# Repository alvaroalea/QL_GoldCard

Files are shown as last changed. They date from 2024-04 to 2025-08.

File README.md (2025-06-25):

# QL_GoldCard
A reverse engineering exercice using the Sinclair QL GoldCard Expansion Card as target

Licensed under Cern OHL-S - https://ohwr.org/cern_ohl_s_v2.txt

(The 3D Model of the PLCC chips is work of Zerover)

## WARNING: DO NOT USE THIS PROJECT IS NOT TESTED AND MISSING THINGS
This is not a functional item, it's only a exercice of reverse engineering to reinforce my skills in Kicad EDA Software.

This project match schematics found on internet, and pictures of the real interface.

* There is no know source of the JEDEC file for the Altera's CPLD
* Some IC can be deprecated and not found on market.
* No information about original has 2 or 4 copper layer, I just use 4, as I was not able to do it in only 2.

Anyway:
* There is not error or warning on the PCB and Schematics
* Schematics seen to be good
* Copper side match 1:1 pictures of internet.

For that:
* If you take the risk and do one and it work, please let me know.
* If you have the source of JEDEC file for the CPLD, please let me know.
* If you found any error in the schematic or PLC, please, let me know.

Two folder
* Original - The design as similar as posible to the Miracles design.
* Alea - new design with new footprints.

## The GoldCard Board
This card is a upgrade of the Sinclair QL computer from 1985, it provide a 68000 processor running a 16Mhz and with a bus wide of 16bit, against original 68008, 7,5Mhz and 8bits bus wide, this is theorically 4 times faster than original QL.

Provide Aditional 1920Mb of Ram (16bits) of 2048Mb installed. (128Kb are used as shadow Rom)

Include a up to 4 disk drive (3 + 1 with a add-on card) compatible with 720Kb, 1.44Mb and 2.88Mb (up to 3.2Mb depend of the format)

It have a Real Time Clock.

This was later superseded by the SuperGoldCard, that use a 68020/24Mhz and 4Mb of Ram.

There area at least 3 Version of the PCB, this is based on the lastes one, version 1 was usually yellow, version 2 and 3 was red color.

Version 1 and 2 have a capacitor solder between CLK and GND under the 68000, and a 3-pad solder jumper under the floppy controller.

CPLD have a sticker over it, "INGOT 6" for version 1 & 2, and "INGOT 5" on Golcard 3

## Comparative
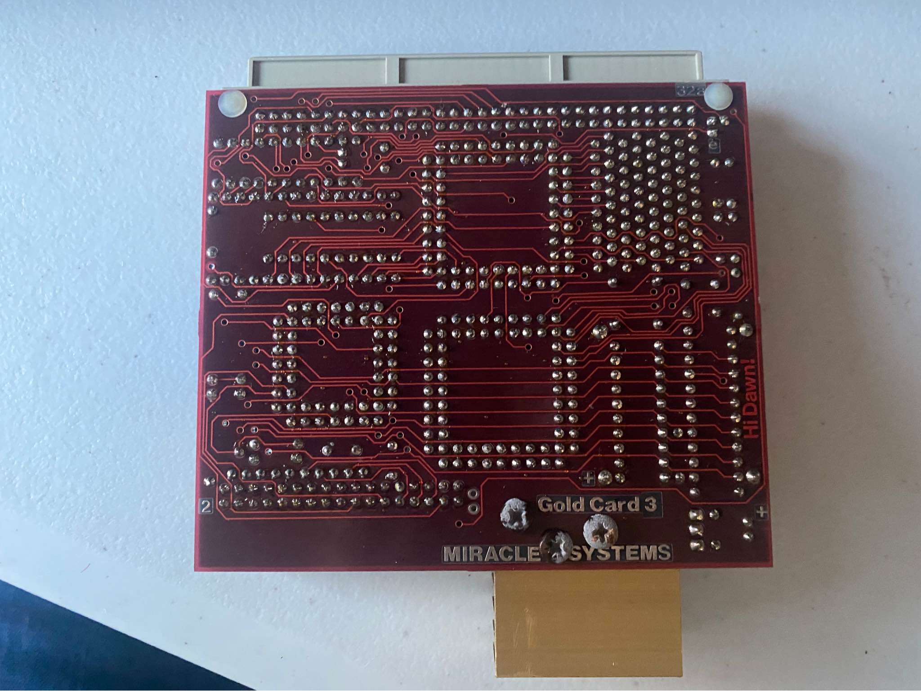
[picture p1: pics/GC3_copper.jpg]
Original Copper Side

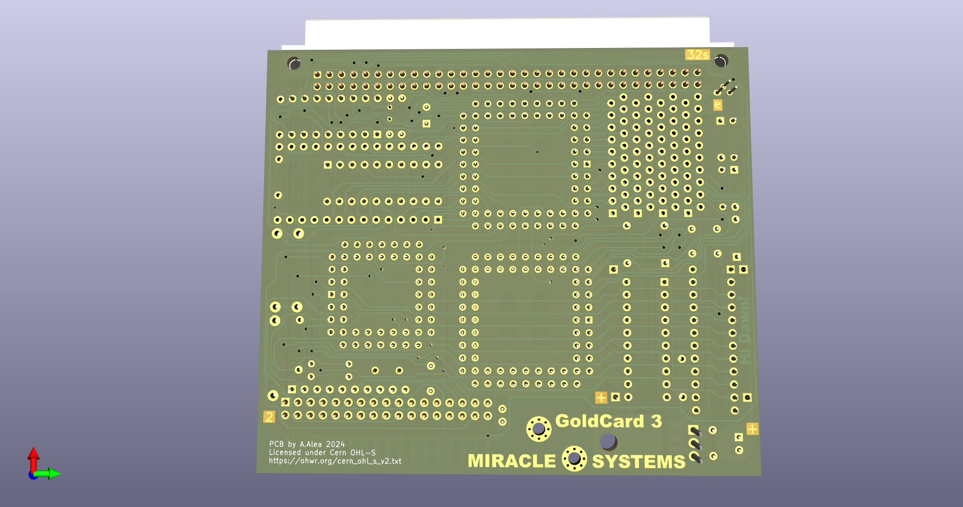
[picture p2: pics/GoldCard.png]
My Copper Side

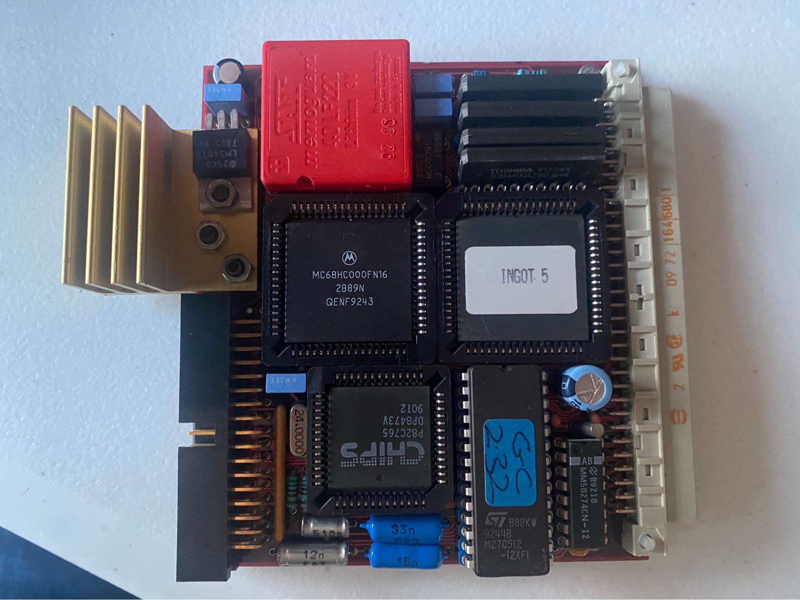
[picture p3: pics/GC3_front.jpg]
Original Components Side

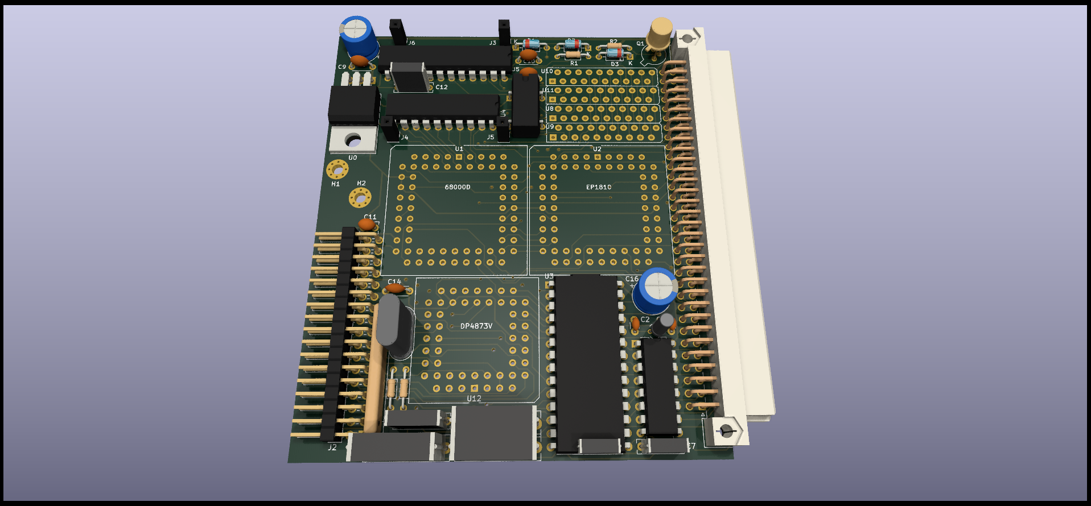
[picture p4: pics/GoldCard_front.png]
My Components Side


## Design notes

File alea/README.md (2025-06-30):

# QL GoldCard (Alea's Version)
A reverse engineering exercice using the Sinclair QL GoldCard Expansion Card as target

Licensed under Cern OHL-S - https://ohwr.org/cern_ohl_s_v2.txt

(The 3D Model of the PLCC chips is work of Zerover)

## WARNING: DO NOT USE THIS PROJECT IS NOT TESTED AND MISSING THINGS
This is not a functional item, it's only a exercice of reverse engineering to reinforce my skills in Kicad EDA Software.

* Use memory SIP-24 easy to found.
* No IC over IC
* small but in market battery socket
* 9V/5V jumpers for use with aurora or backplanes.

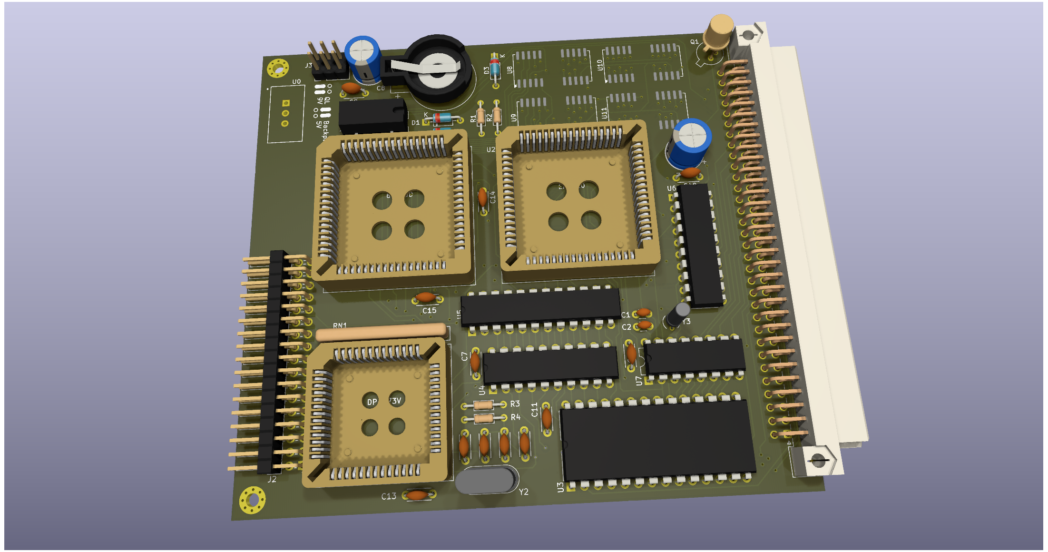
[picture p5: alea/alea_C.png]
My Components Side

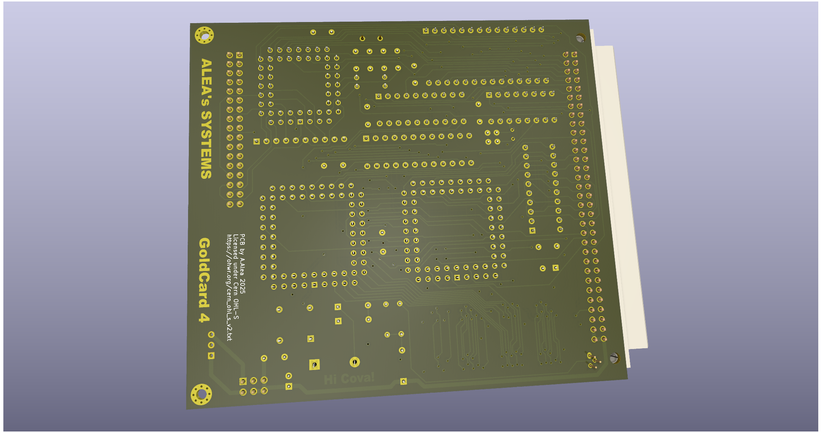
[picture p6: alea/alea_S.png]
My Copper Side


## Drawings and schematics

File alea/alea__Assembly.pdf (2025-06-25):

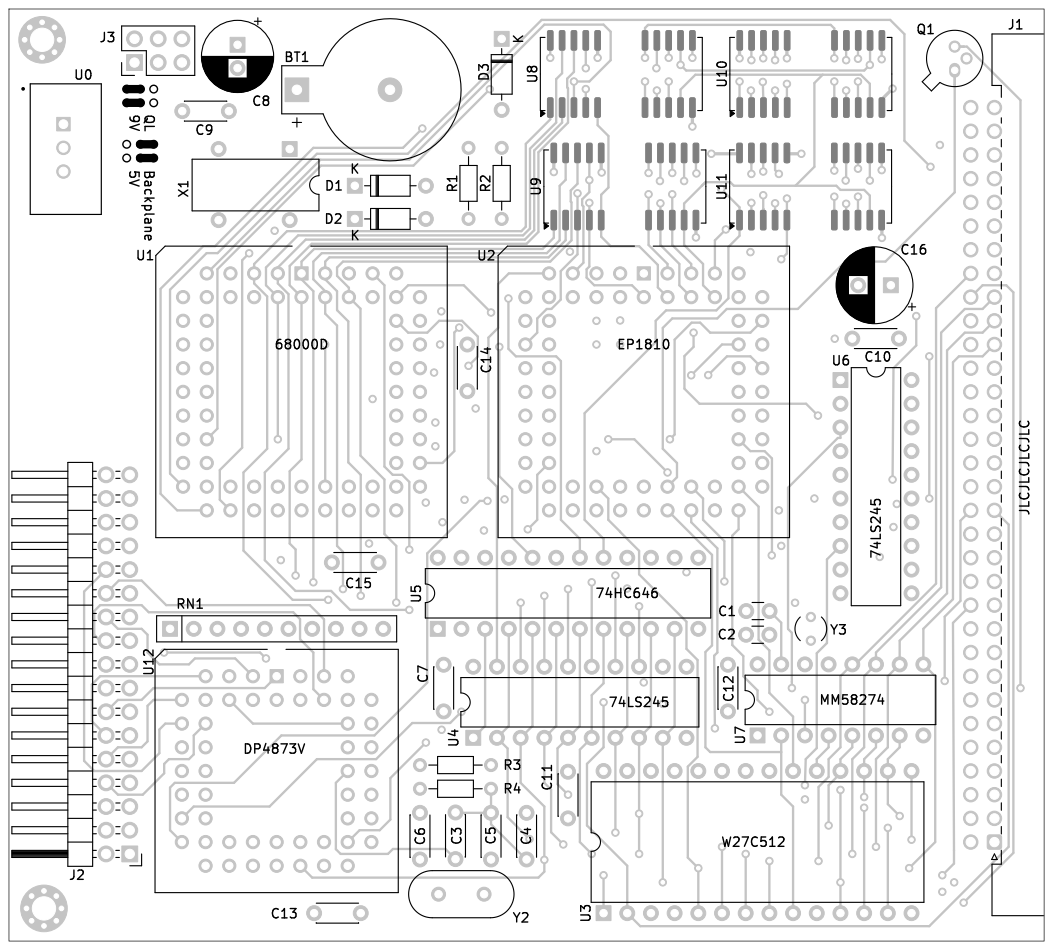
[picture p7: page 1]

Id: /1 Title: Sinclair QL Gold Card 3

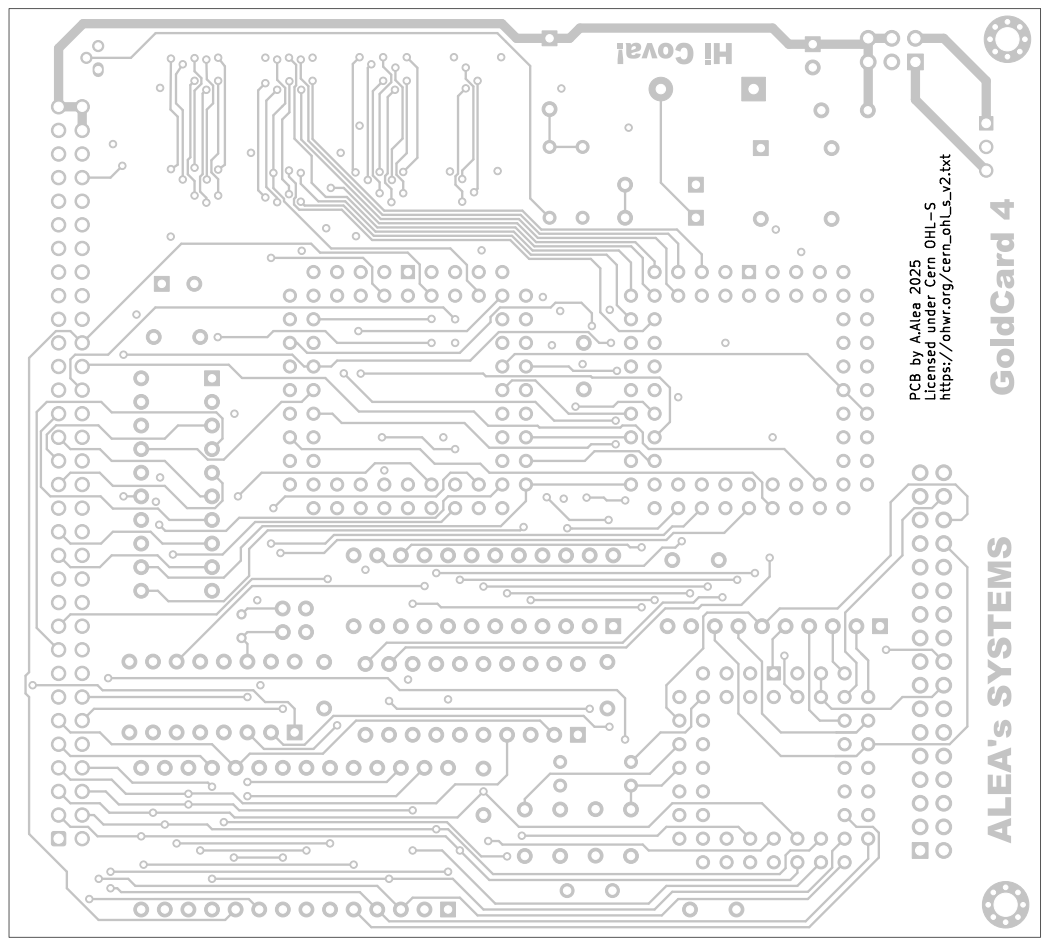
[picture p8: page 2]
D Date: 2024-04-14 KiCad; E.D.A. 9.0.2 Size: A4; Rev: 0.0; File: alea.kicad_pcb Sheet: Black; And; White; BOT Alvaro Alea Based; on schematic; from tetroid; Licensed; under Cern OHL-S -; https://ohwr.org/cern_ohl_s_v2.txt Board2Pdf:; Black; BOT -; Page 2/4

PCB by A.Alea 2025 Licensed under Cern OHL-S https://ohwr.org/cern_ohl_s_v2.txt

Id: /1 Title: Sinclair QL Gold Card 3

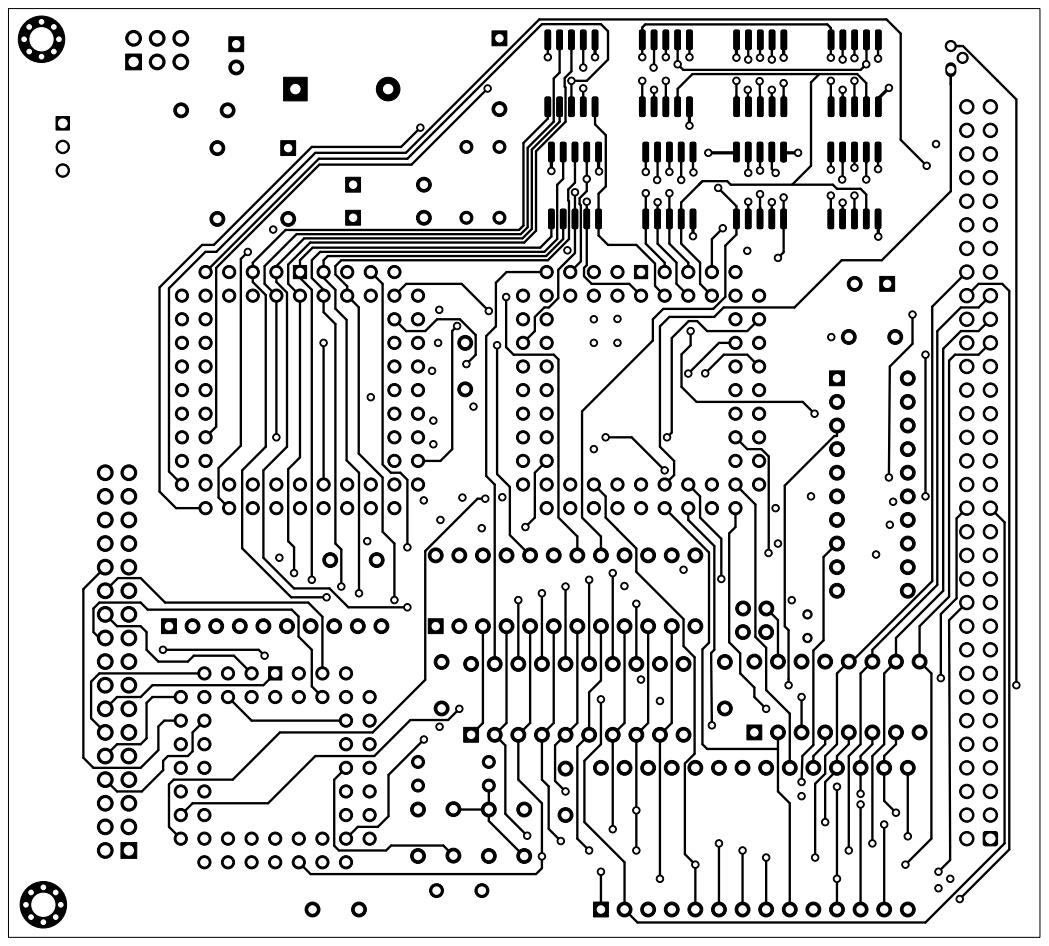
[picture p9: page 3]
D Date: 2024-04-14 KiCad; E.D.A. 9.0.2 Size: A4; Rev: 0.0; File: alea.kicad_pcb Sheet: Black; And; White; TOP-Tracks Alvaro Alea Based; on schematic; from tetroid; Licensed; under Cern OHL-S -; https://ohwr.org/cern_ohl_s_v2.txt Board2Pdf:; Black; TOP-Tracks; Page 3/4

Id: /1 Title: Sinclair QL Gold Card 3

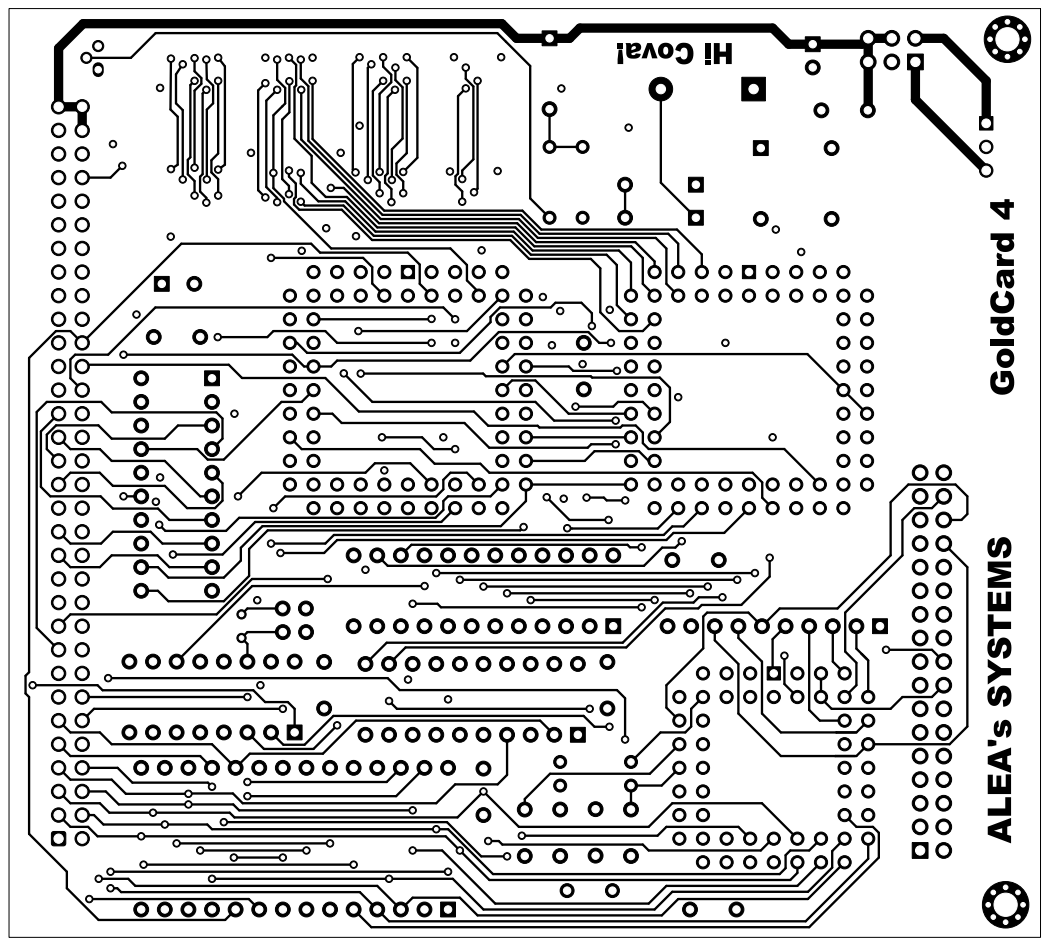
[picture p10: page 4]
D Date: 2024-04-14 KiCad; E.D.A. 9.0.2 Size: A4; Rev: 0.0; File: alea.kicad_pcb Sheet: Black; And; White; BOT-Tracks Alvaro Alea Based; on schematic; from tetroid; Licensed; under Cern OHL-S -; https://ohwr.org/cern_ohl_s_v2.txt Board2Pdf:; Black; BOT-Tracks; Page 4/4

Id: /1 Title: Sinclair QL Gold Card 3

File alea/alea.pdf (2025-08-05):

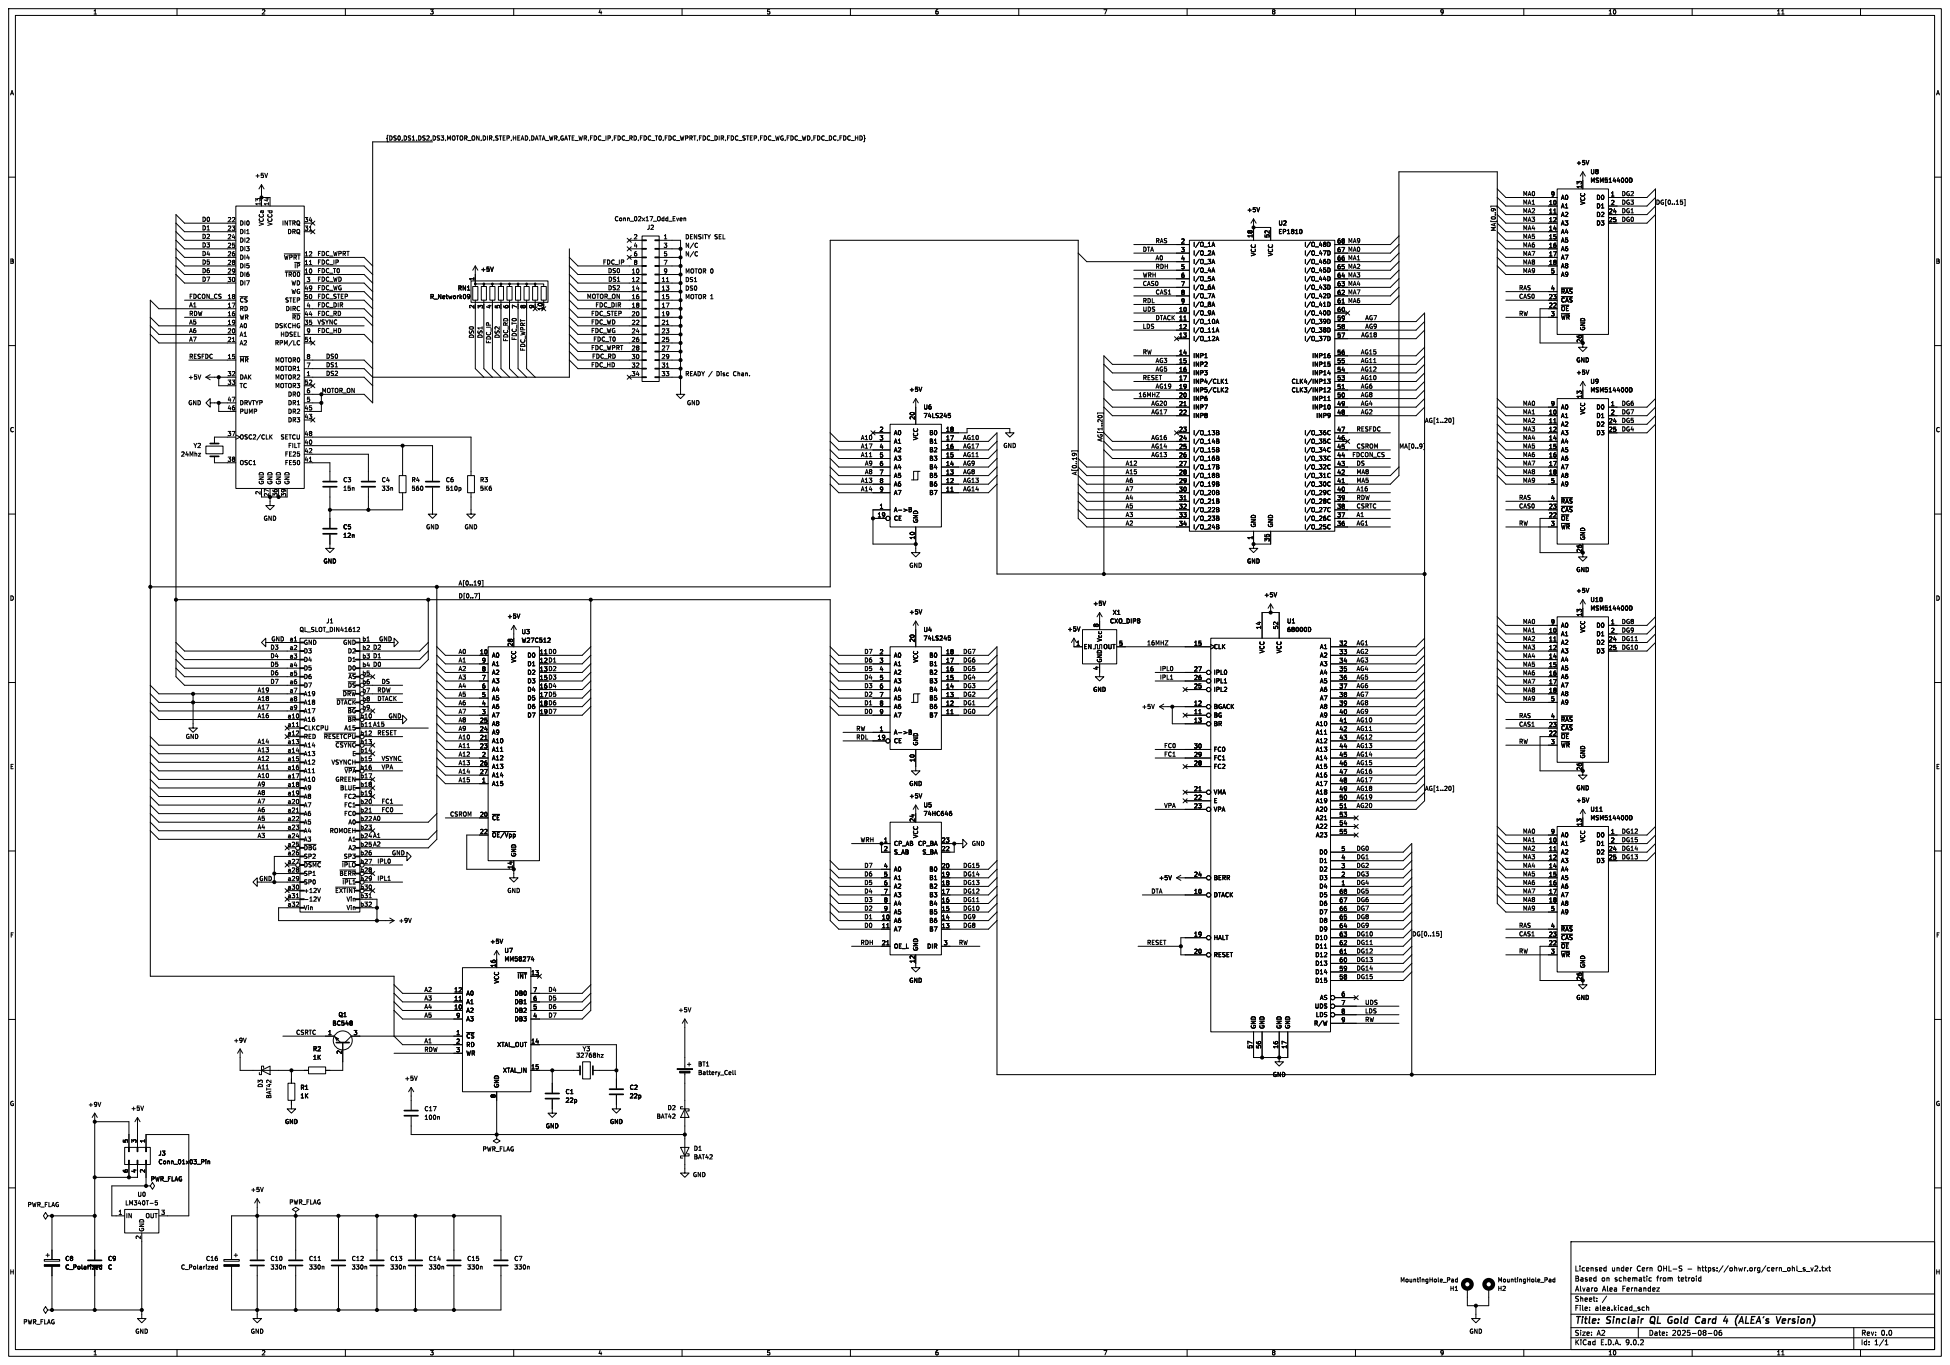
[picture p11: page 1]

+5V GND GND GND GND

2 VCCd 14 GND 27 GND 36 GND 39

J2 Conn_02x17_Odd_Even
DS1 MOTOR 0 MOTOR 1 DS0 READY / Disc Chan. DENSITY SEL

910 +5V U3 W27C512 A0 10 A1 9 A2 8 A3 7 A4 6 A5 5 A6 4 A7 3 A8 25 A9 24 A10 21 A11 23 A12 2 A13 26 A14 27 A15 1 ~{CE} 20 ~{OE/Vpp} 22 VCC 28 GND 14 D0 11 D1 12 D2 13 D3 15 D4 16 D5 17 D6 18 D7 19 +5V

b14 VSYNCH b15 ~{VPA}b16 GREEN b17 BLUE b18 FC2 b19 FC1 b20 FC0 b21 A0 b22 ROMOEH b23 A1 b24 A2 b25 SP3 b26 ~{IPLO}b27 ~{BERR}b28 ~{IPL1}b29 ~{EXTINT}b30 Vin b31 Vin b32

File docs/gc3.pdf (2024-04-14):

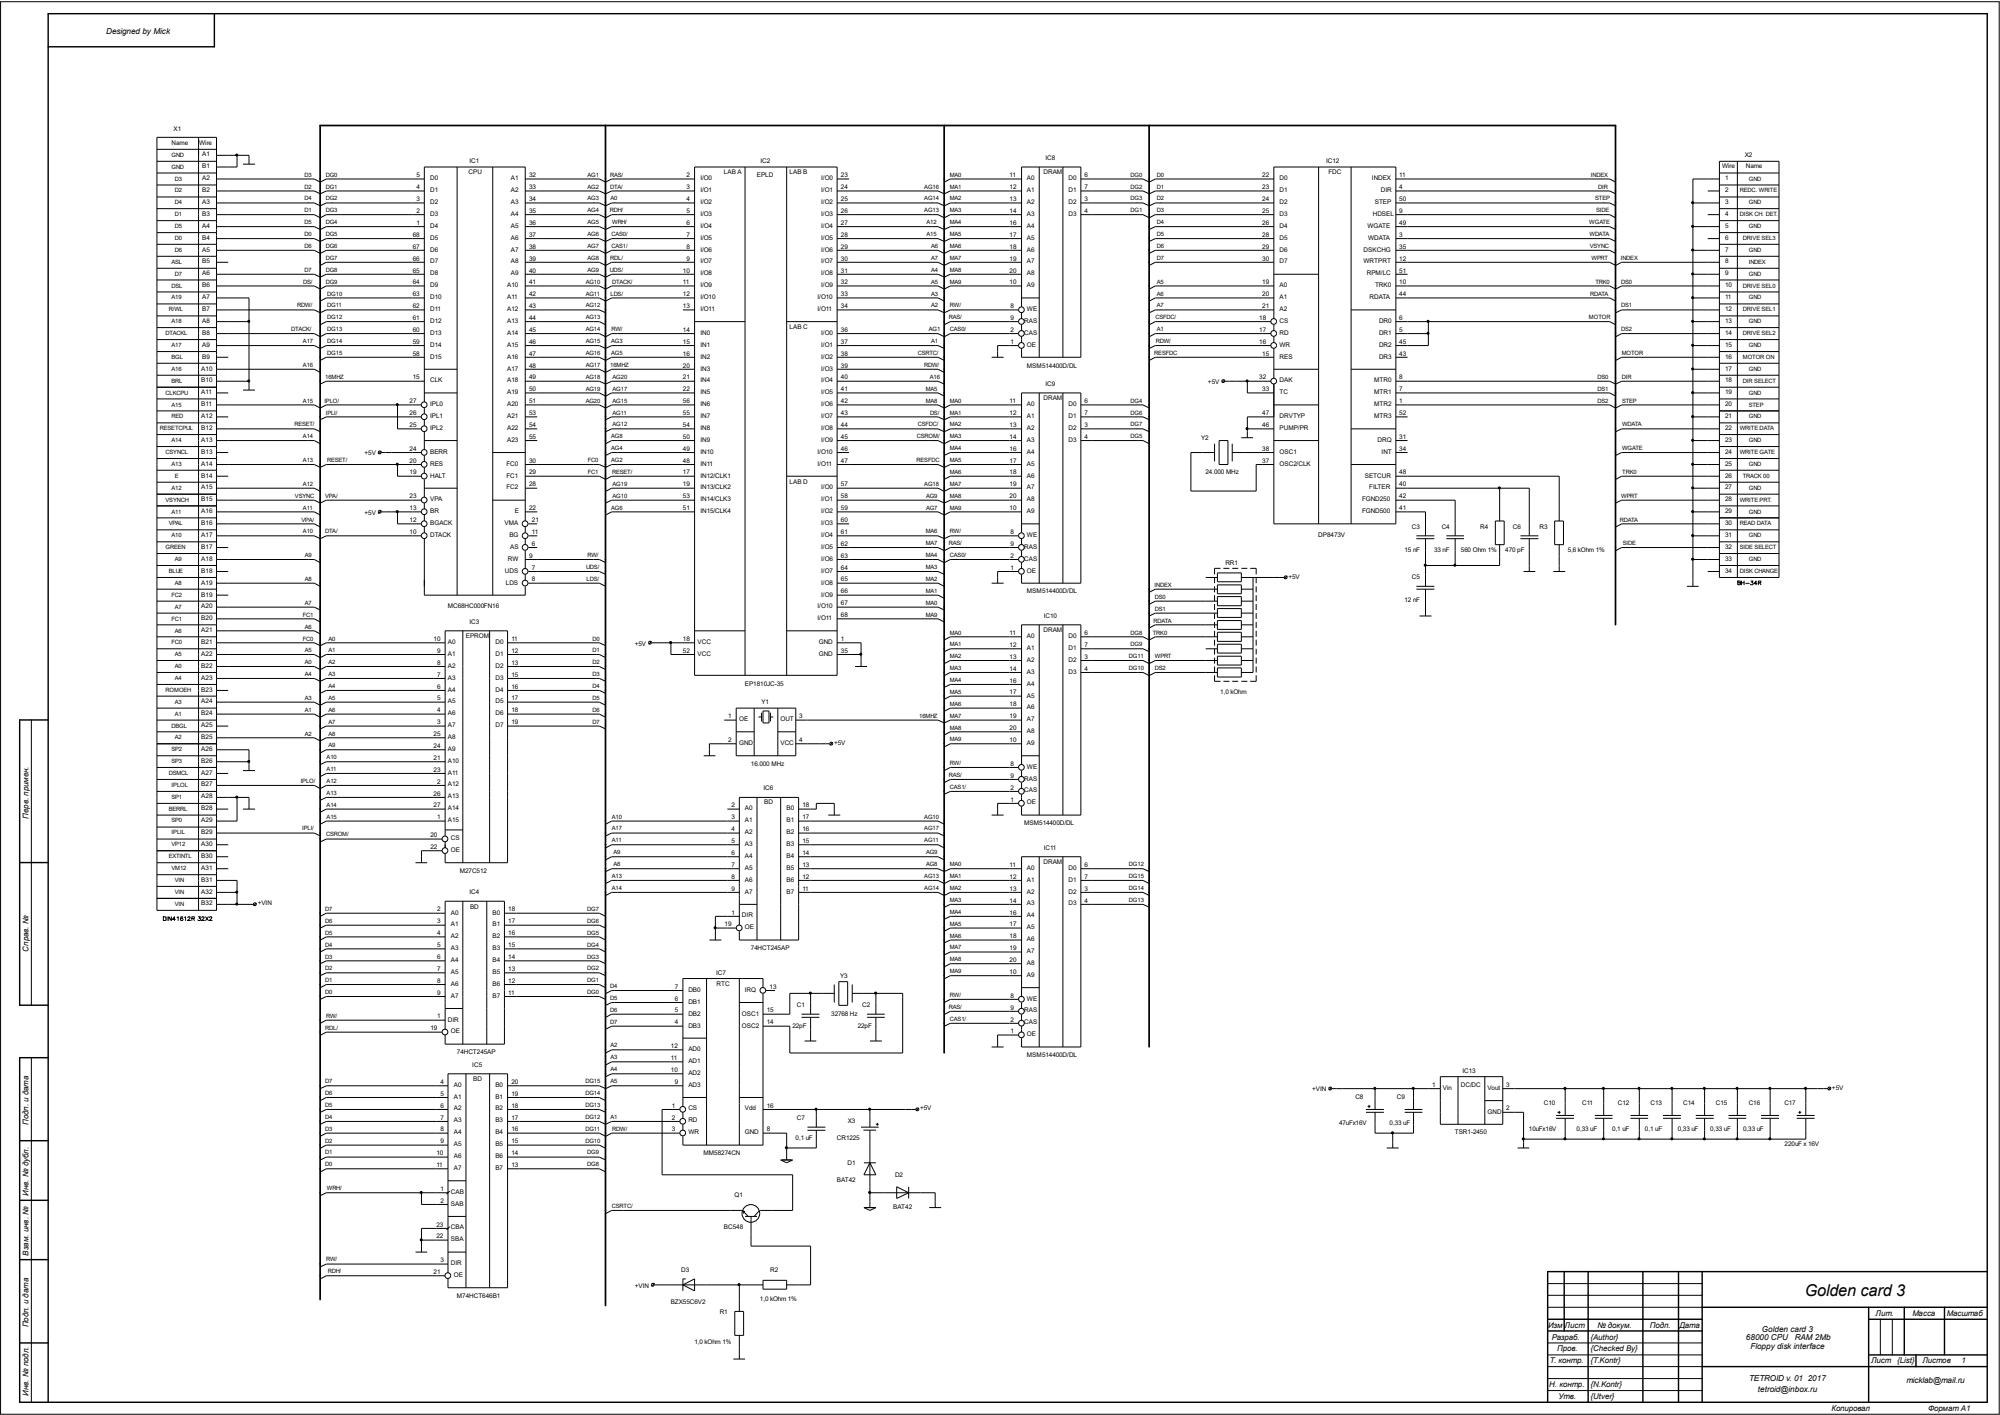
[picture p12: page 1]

Name | Wire

GND | A1

Инв. № подл. Подп. и дата Взам. инв. № Справ. № Перв. примен.

DSMCL | A27

IPLOL | B27

Инв. № дубл. Подп. и дата

Golden card 3

Golden card 3 68000 CPU RAM 2Mb Floppy disk interface | Лит. | Масса | Масштаб

Изм Лист | | № докум. | Подп. | Дата
Разраб. | | {Author}
Пров. | | {Checked By}
Т. контр. | {T.Kontr} | | | | Лист {List} | Листов 1

TETROID v. 01 2017 tetroid@inbox.ru | micklab@mail.ru

Н. контр. | {N.Kontr}
Утв. | {Utver}

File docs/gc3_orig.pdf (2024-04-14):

### Designed by Mick

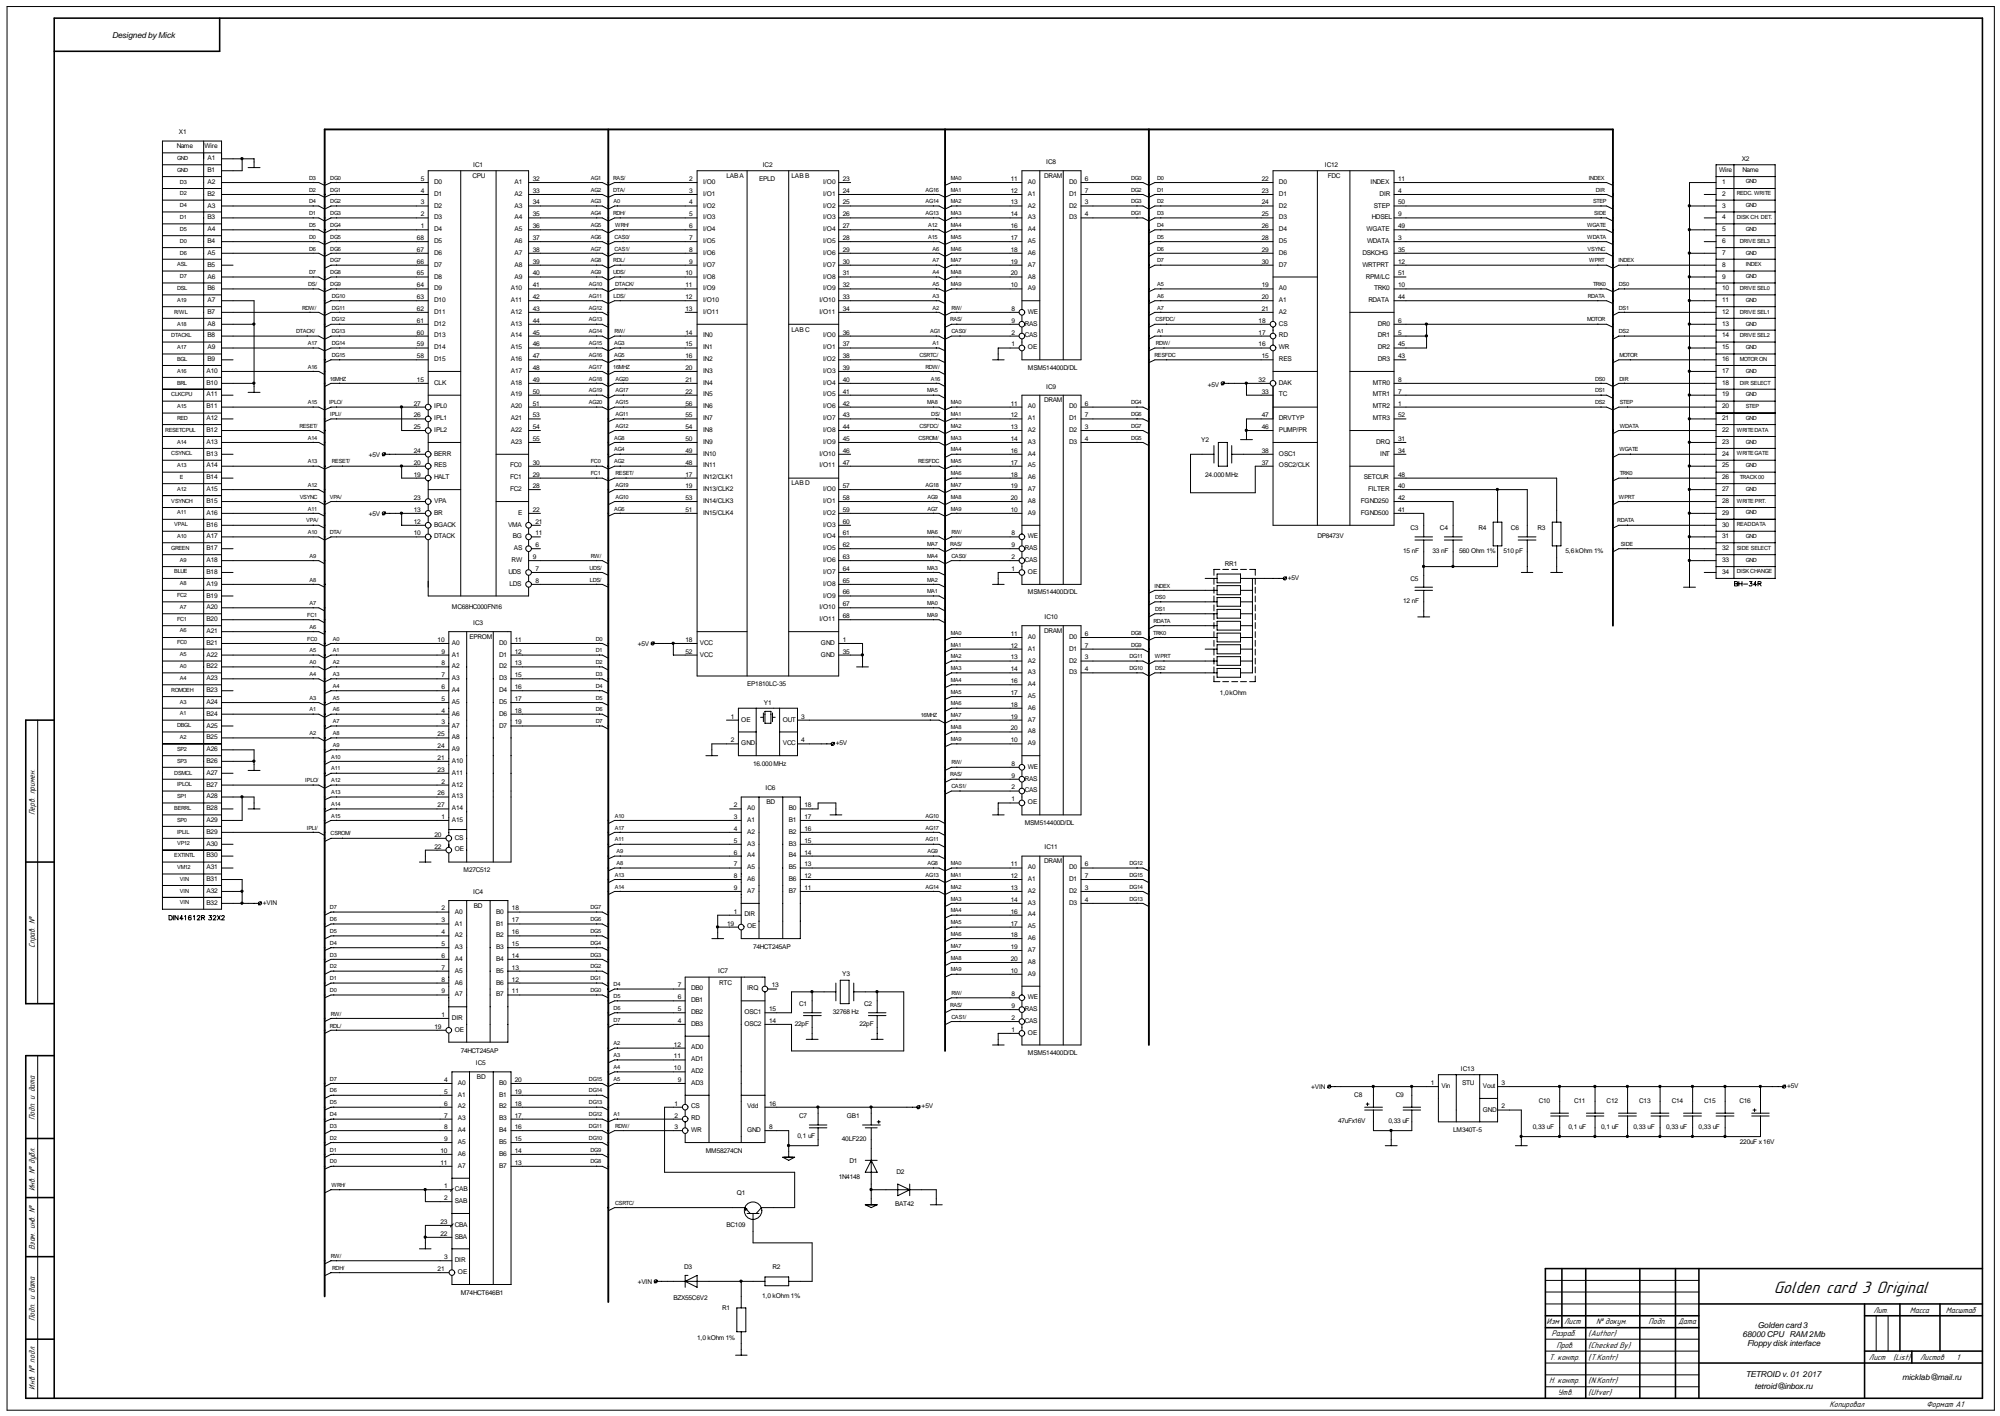
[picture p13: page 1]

A6
FC0 | B21

VCC | GND

Èíâ. ¹ ïîäë. Ïîäï. è äàòà Âçàì. èíâ. ¹ Ñïðàâ. ¹ Ïåðâ. ïðèìåí.

DSMCL | A27

IPLOL | B27

VIN | B32

VIN | A32

Èíâ. ¹ äóáë. Ïîäï. è äàòà

Golden card 3 Original

Èçì Ðàçðàá. Ïðîâ. Ò. êîíòð. | ¹ äîêóì. {Author} {Checked By} {T.Kontr} | Ïîäï. | Äàòà Ëèñò Golden card 3 68000 CPU RAM 2Mb Floppy disk interface | Ëèò. Ìàññà Ìàñøòàá

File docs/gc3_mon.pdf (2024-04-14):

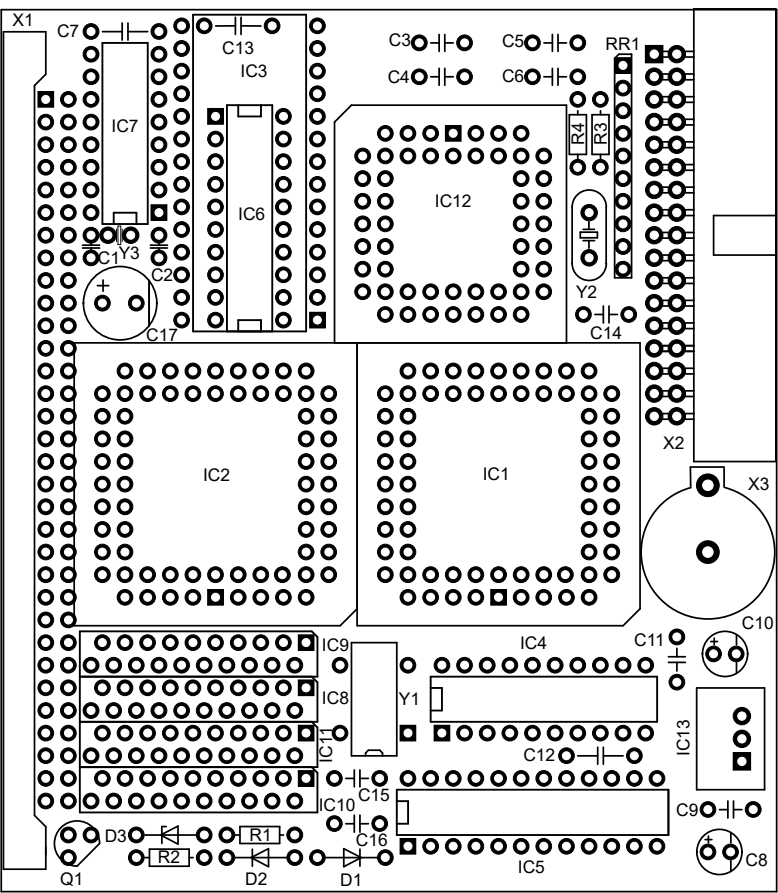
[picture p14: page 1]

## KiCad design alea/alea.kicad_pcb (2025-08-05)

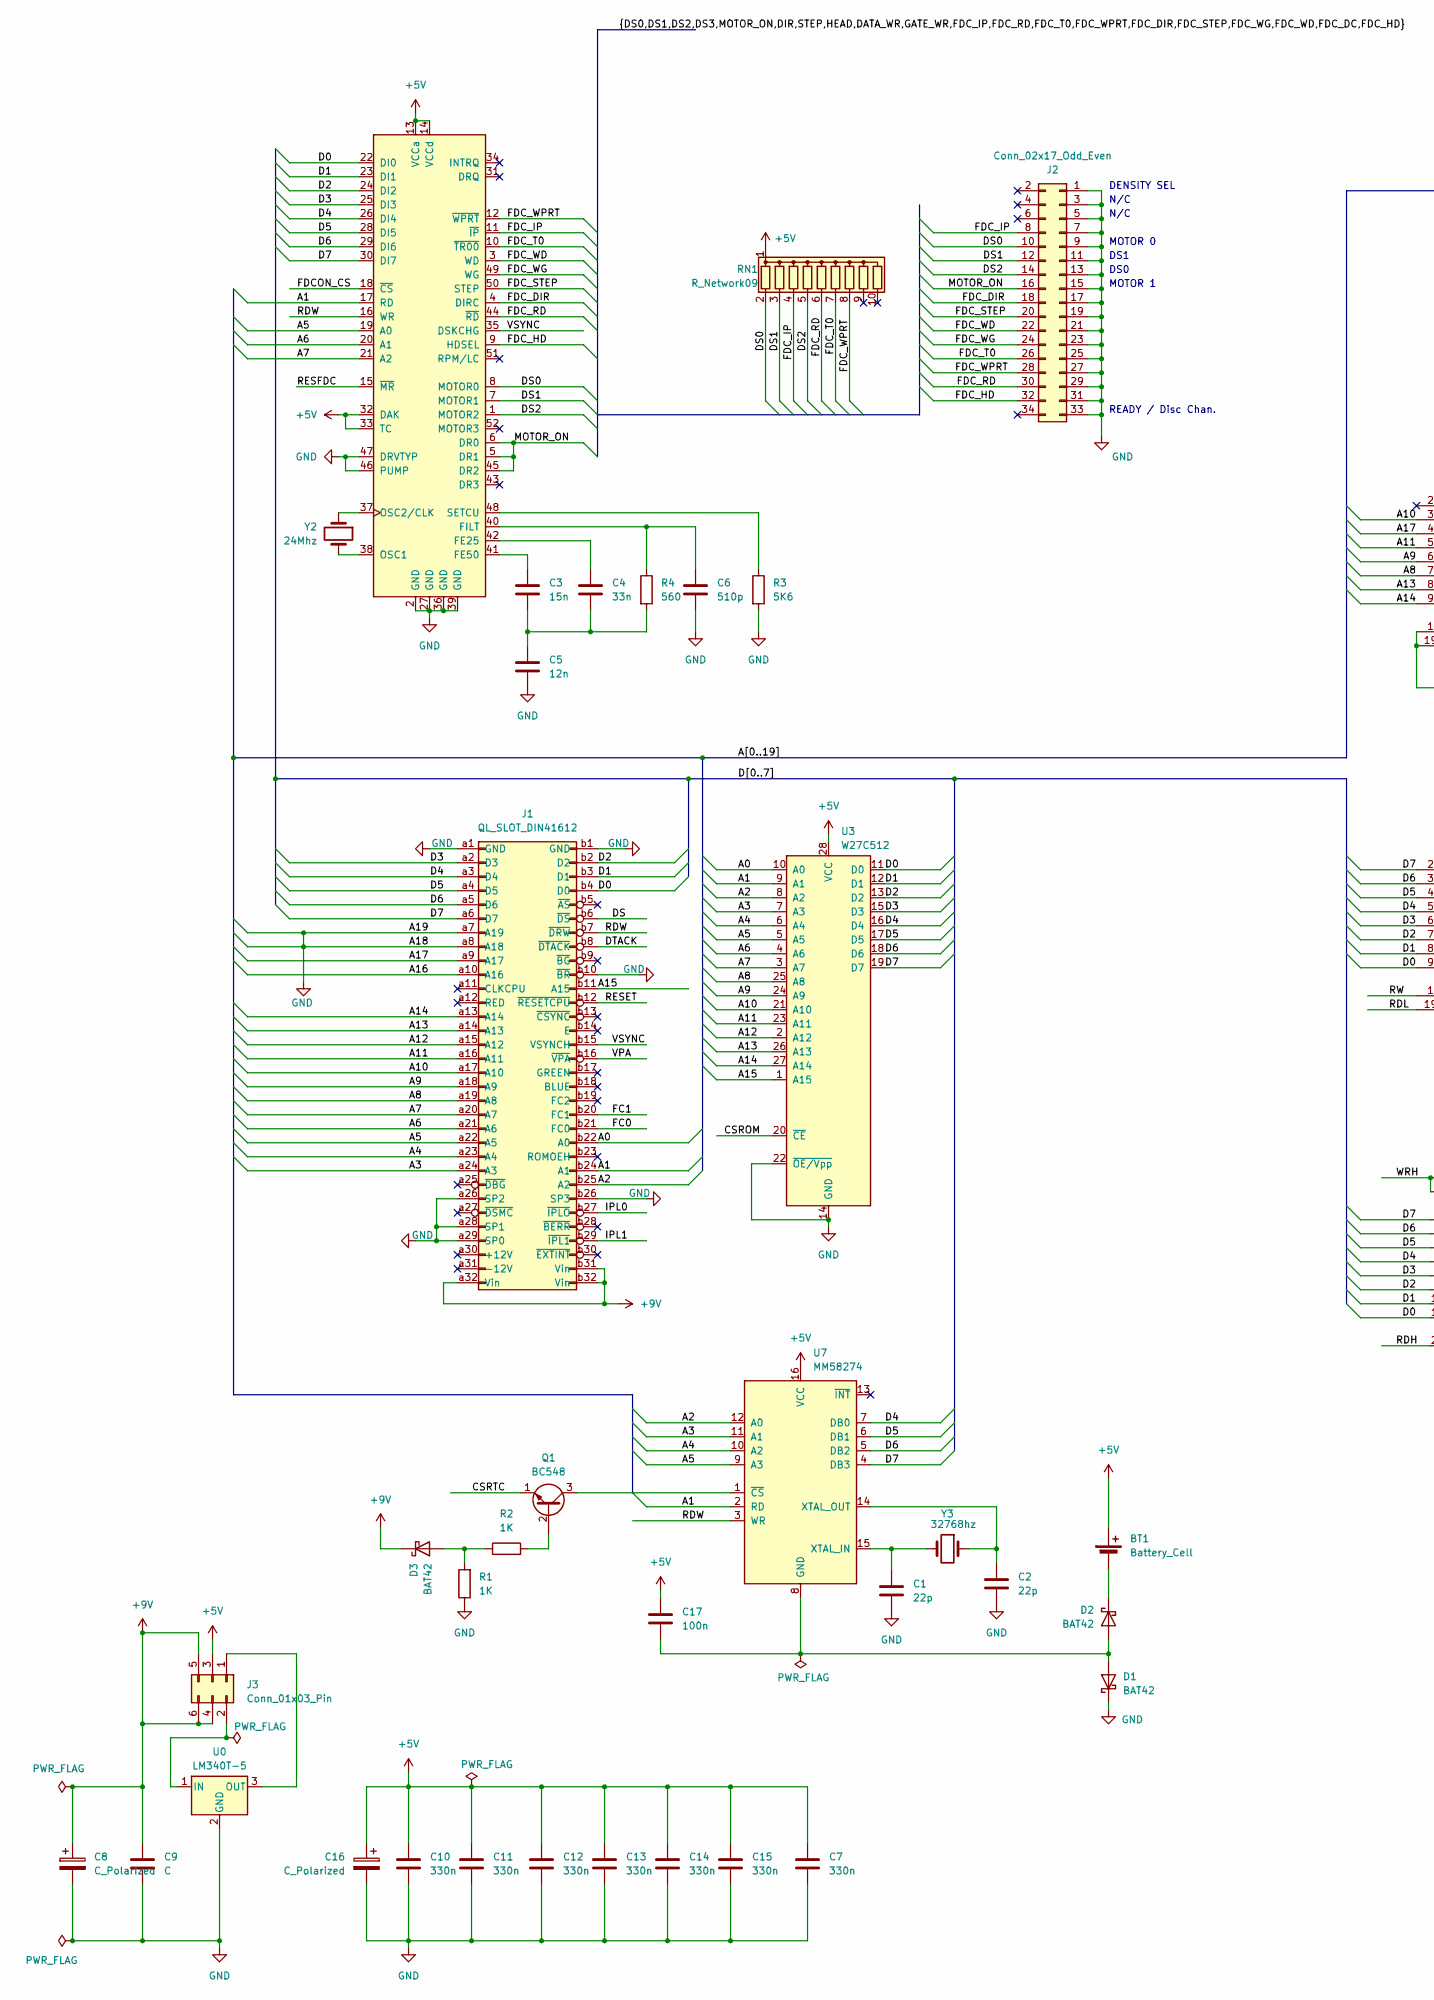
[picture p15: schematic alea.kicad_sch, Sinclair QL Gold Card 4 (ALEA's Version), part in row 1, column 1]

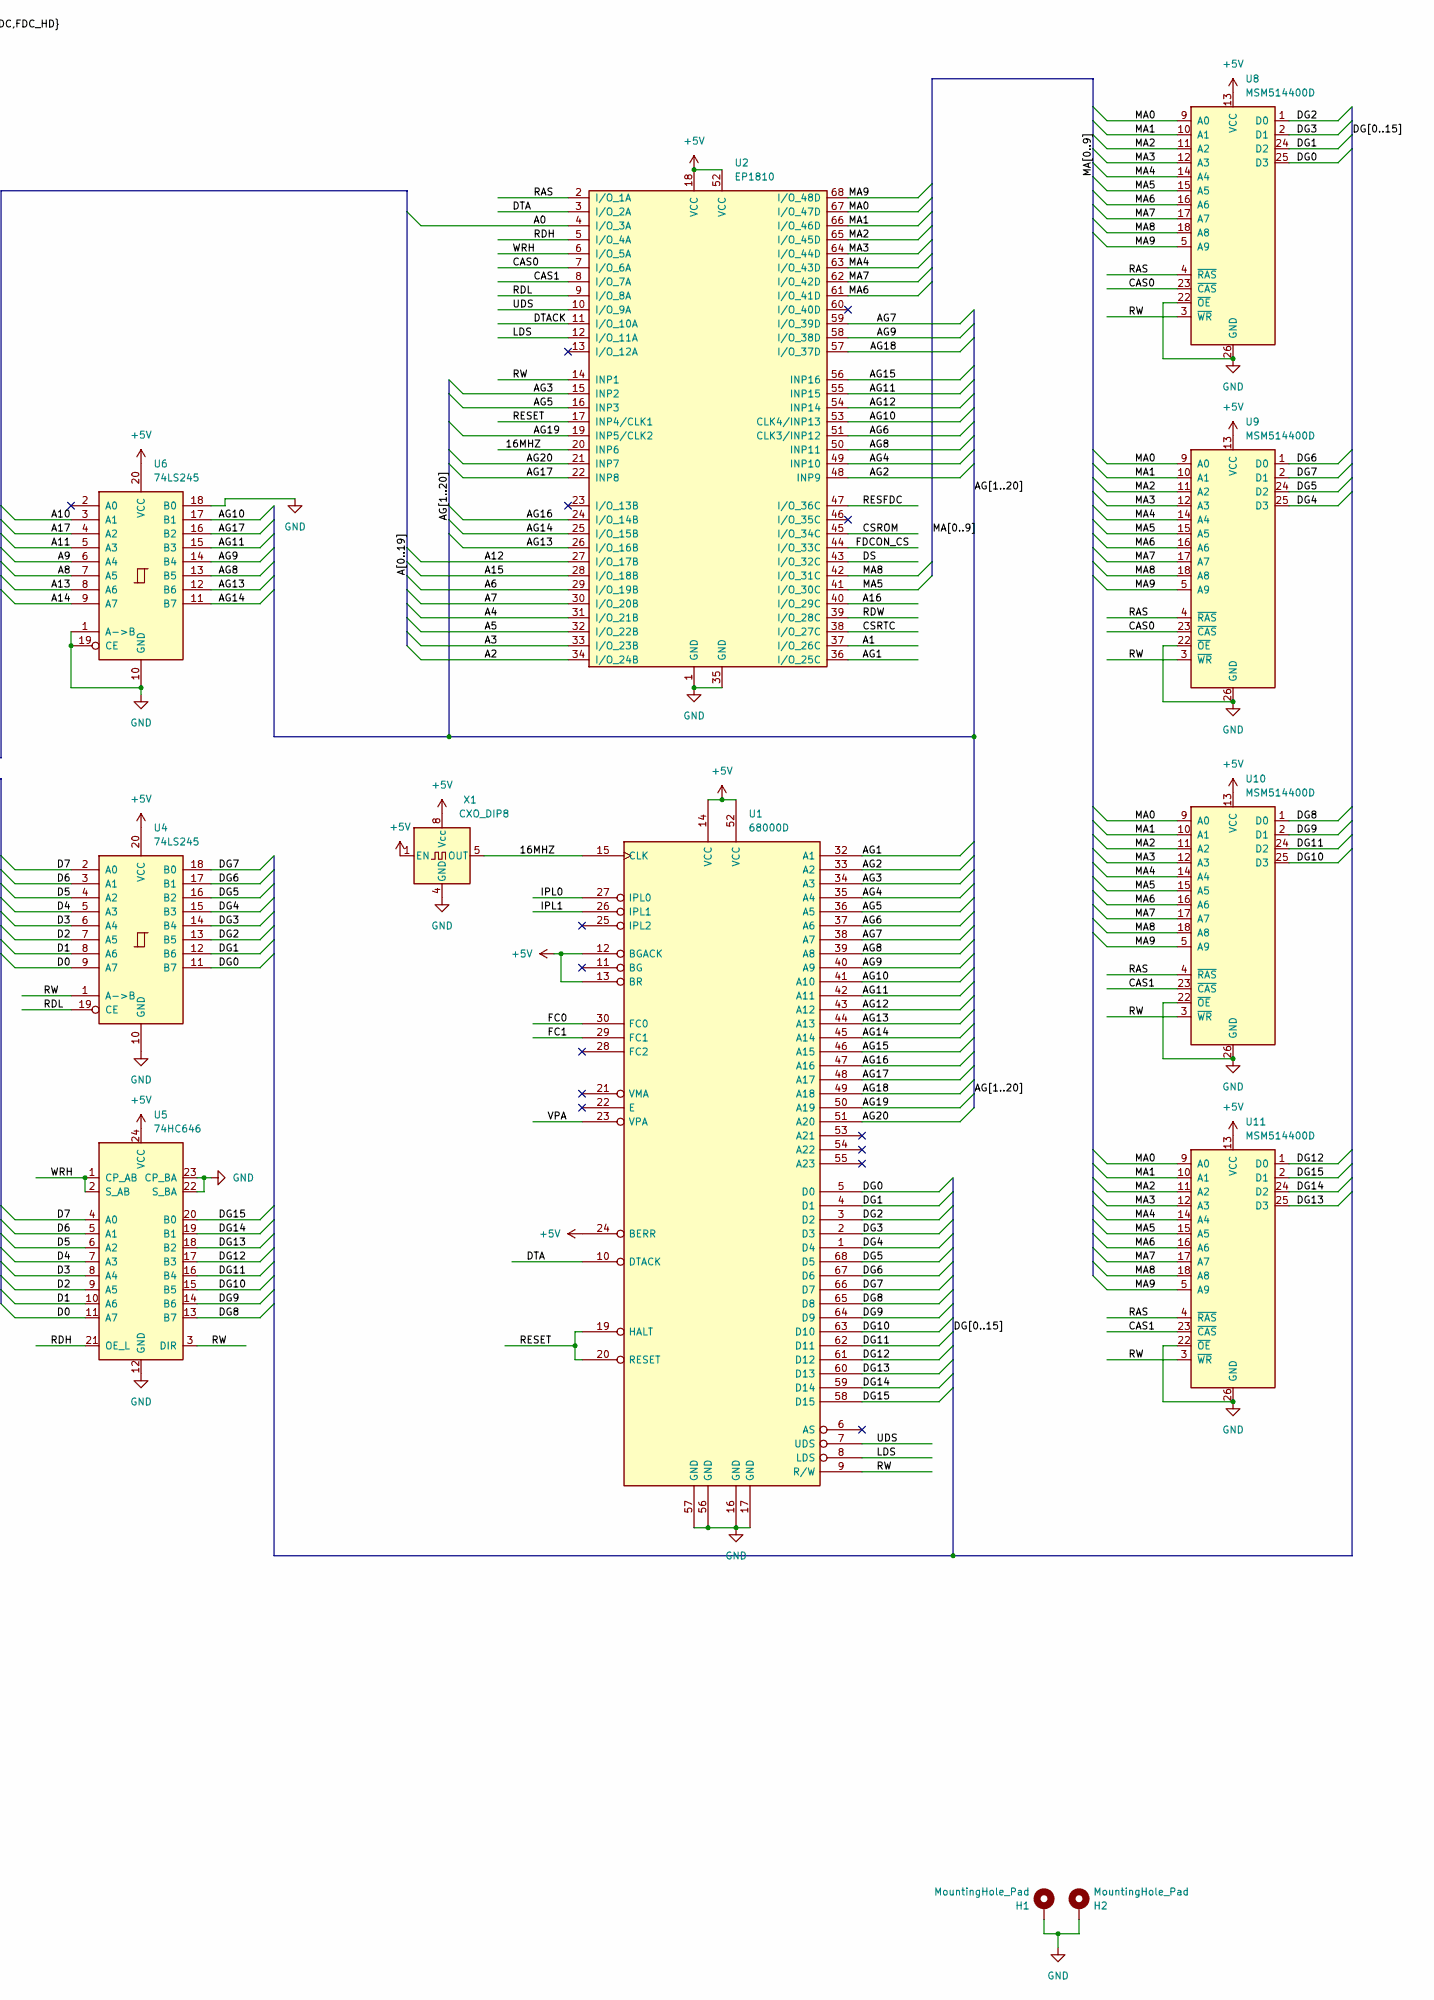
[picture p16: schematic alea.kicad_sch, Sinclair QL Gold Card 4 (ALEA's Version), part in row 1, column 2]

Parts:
BT1: Battery_Cell; BatteryHolder_Keystone_500
C1, C2: 22p; C_Disc_D3.0mm_W1.6mm_P2.50mm
C3: 15n; C_Disc_D4.3mm_W1.9mm_P5.00mm
C4: 33n; C_Disc_D4.3mm_W1.9mm_P5.00mm
C5: 12n; C_Disc_D4.3mm_W1.9mm_P5.00mm
C6: 510p; C_Disc_D4.3mm_W1.9mm_P5.00mm
C7, C10, C11, C12, C13, C14, C15: 330n; C_Disc_D4.3mm_W1.9mm_P5.00mm
C8: C_Polarized; CP_Radial_D7.5mm_P2.50mm
C9: C; C_Disc_D4.3mm_W1.9mm_P5.00mm
C16: C_Polarized; CP_Radial_D8.0mm_P3.50mm
C17: 100n; C_Disc_D4.3mm_W1.9mm_P5.00mm
D1, D2, D3: BAT42; D_DO-35_SOD27_P7.62mm_Horizontal
H1, H2: MountingHole_Pad; MountingHole_2.5mm_Pad_Via
J1: QL_SLOT_DIN41612; DIN41612_B_2x32_Female_Horizontal_THT
J2: Conn_02x17_Odd_Even; PinHeader_2x17_P2.54mm_Horizontal
J3: Conn_01x03_Pin; PinHeader_2x03_P2.54mm_Vertical
Q1: BC548; TO-18-3
R1, R2: 1K; R_Axial_DIN0204_L3.6mm_D1.6mm_P7.62mm_Horizontal
R3: 5K6; R_Axial_DIN0204_L3.6mm_D1.6mm_P7.62mm_Horizontal
R4: 560; R_Axial_DIN0204_L3.6mm_D1.6mm_P7.62mm_Horizontal
RN1: R_Network09; R_Array_SIP10
U0: LM340T-5; CONV_TSR_2-2450
U1: 68000D; PLCC-68_THT-Socket
U2: EP1810; PLCC-68_THT-Socket
U3: W27C512; DIP-28_W15.24mm
U4, U6: 74LS245; DIP-20_W7.62mm
U5: 74HC646; DIP-24_W7.62mm
U7: MM58274; DIP-16_W7.62mm
U8, U9, U10, U11: MSM514400D; SOJ-26_7.62x18.415mm_P1.27mm
U12: DP4873V; PLCC-52_THT-Socket
X1: CXO_DIP8; Oscillator_SeikoEpson_SG-8002DC
Y2: 24Mhz; Crystal_HC49-U_Vertical
Y3: 32768hz; Crystal_AT310_D3.0mm_L10.0mm_Vertical

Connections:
+5V: BT1.1 (+), C7.1, C10.1, C11.1, C12.1, C13.1, C14.1, C15.1, C16.1, C17.1, J3.3, RN1.1 (common), U1.12 (BGACK), U1.13 (BR), U1.14 (VCC), U1.24 (BERR), U1.52 (VCC), U2.18 (VCC), U2.52 (VCC), U3.28 (VCC), U4.20 (VCC), U5.24 (VCC), U6.20 (VCC), U7.16 (VCC), U8.13 (VCC), U9.13 (VCC), U10.13 (VCC), U11.13 (VCC), U12.13 (VCCa), U12.14 (VCCd), U12.32 (DAK), U12.33 (TC), X1.1 (EN), X1.8 (Vcc)
+9V: C8.1, C9.1, D3.1 (K), J1.a32 (Vin), J1.b31 (Vin), J1.b32 (Vin), J3.4, J3.5, J3.6
/16MHZ: U1.15 (CLK), U2.20 (INP6), X1.5 (OUT)
/A0: J1.b22 (A0), U2.4 (I/O_3A), U3.10 (A0)
/A1: J1.b24 (A1), U2.37 (I/O_26C), U3.9 (A1), U7.2 (RD), U12.17 (RD)
/A2: J1.b25 (A2), U2.34 (I/O_24B), U3.8 (A2), U7.12 (A0)
/A3: J1.a24 (A3), U2.33 (I/O_23B), U3.7 (A3), U7.11 (A1)
/A4: J1.a23 (A4), U2.31 (I/O_21B), U3.6 (A4), U7.10 (A2)
/A5: J1.a22 (A5), U2.32 (I/O_22B), U3.5 (A5), U7.9 (A3), U12.19 (A0)
/A6: J1.a21 (A6), U2.29 (I/O_19B), U3.4 (A6), U12.20 (A1)
/A7: J1.a20 (A7), U2.30 (I/O_20B), U3.3 (A7), U12.21 (A2)
/A8: J1.a19 (A8), U3.25 (A8), U6.7 (A5)
/A9: J1.a18 (A9), U3.24 (A9), U6.6 (A4)
/A10: J1.a17 (A10), U3.21 (A10), U6.3 (A1)
/A11: J1.a16 (A11), U3.23 (A11), U6.5 (A3)
/A12: J1.a15 (A12), U2.27 (I/O_17B), U3.2 (A12)
/A13: J1.a14 (A13), U3.26 (A13), U6.8 (A6)
/A14: J1.a13 (A14), U3.27 (A14), U6.9 (A7)
/A15: J1.b11 (A15), U2.28 (I/O_18B), U3.1 (A15)
/A16: J1.a10 (A16), U2.40 (I/O_29C)
/A17: J1.a9 (A17), U6.4 (A2)
/AG1: U1.32 (A1), U2.36 (I/O_25C)
/AG2: U1.33 (A2), U2.48 (INP9)
/AG3: U1.34 (A3), U2.15 (INP2)
/AG4: U1.35 (A4), U2.49 (INP10)
/AG5: U1.36 (A5), U2.16 (INP3)
/AG6: U1.37 (A6), U2.51 (CLK3/INP12)
/AG7: U1.38 (A7), U2.59 (I/O_39D)
/AG8: U1.39 (A8), U2.50 (INP11), U6.13 (B5)
/AG9: U1.40 (A9), U2.58 (I/O_38D), U6.14 (B4)
/AG10: U1.41 (A10), U2.53 (CLK4/INP13), U6.17 (B1)
/AG11: U1.42 (A11), U2.55 (INP15), U6.15 (B3)
/AG12: U1.43 (A12), U2.54 (INP14)
/AG13: U1.44 (A13), U2.26 (I/O_16B), U6.12 (B6)
/AG14: U1.45 (A14), U2.25 (I/O_15B), U6.11 (B7)
/AG15: U1.46 (A15), U2.56 (INP16)
/AG16: U1.47 (A16), U2.24 (I/O_14B)
/AG17: U1.48 (A17), U2.22 (INP8), U6.16 (B2)
/AG18: U1.49 (A18), U2.57 (I/O_37D)
/AG19: U1.50 (A19), U2.19 (INP5/CLK2)
/AG20: U1.51 (A20), U2.21 (INP7)
/CAS0: U2.7 (I/O_6A), U8.23 (~CAS), U9.23 (~CAS)
/CAS1: U2.8 (I/O_7A), U10.23 (~CAS), U11.23 (~CAS)
/CSROM: U2.45 (I/O_34C), U3.20 (~CE)
/CSRTC: Q1.1 (E), U2.38 (I/O_27C)
/D0: J1.b4 (D0), U3.11 (D0), U4.9 (A7), U5.11 (A7), U12.22 (DI0)
/D1: J1.b3 (D1), U3.12 (D1), U4.8 (A6), U5.10 (A6), U12.23 (DI1)
/D2: J1.b2 (D2), U3.13 (D2), U4.7 (A5), U5.9 (A5), U12.24 (DI2)
/D3: J1.a2 (D3), U3.15 (D3), U4.6 (A4), U5.8 (A4), U12.25 (DI3)
/D4: J1.a3 (D4), U3.16 (D4), U4.5 (A3), U5.7 (A3), U7.7 (DB0), U12.26 (DI4)
/D5: J1.a4 (D5), U3.17 (D5), U4.4 (A2), U5.6 (A2), U7.6 (DB1), U12.28 (DI5)
/D6: J1.a5 (D6), U3.18 (D6), U4.3 (A1), U5.5 (A1), U7.5 (DB2), U12.29 (DI6)
/D7: J1.a6 (D7), U3.19 (D7), U4.2 (A0), U5.4 (A0), U7.4 (DB3), U12.30 (DI7)
/DG0: U1.5 (D0), U4.11 (B7), U8.25 (D3)
/DG1: U1.4 (D1), U4.12 (B6), U8.24 (D2)
/DG2: U1.3 (D2), U4.13 (B5), U8.1 (D0)
/DG3: U1.2 (D3), U4.14 (B4), U8.2 (D1)
/DG4: U1.1 (D4), U4.15 (B3), U9.25 (D3)
/DG5: U1.68 (D5), U4.16 (B2), U9.24 (D2)
/DG6: U1.67 (D6), U4.17 (B1), U9.1 (D0)
/DG7: U1.66 (D7), U4.18 (B0), U9.2 (D1)
/DG8: U1.65 (D8), U5.13 (B7), U10.1 (D0)
/DG9: U1.64 (D9), U5.14 (B6), U10.2 (D1)
/DG10: U1.63 (D10), U5.15 (B5), U10.25 (D3)
/DG11: U1.62 (D11), U5.16 (B4), U10.24 (D2)
/DG12: U1.61 (D12), U5.17 (B3), U11.1 (D0)
/DG13: U1.60 (D13), U5.18 (B2), U11.25 (D3)
/DG14: U1.59 (D14), U5.19 (B1), U11.24 (D2)
/DG15: U1.58 (D15), U5.20 (B0), U11.2 (D1)
/DS: J1.b6 (~DS), U2.43 (I/O_32C)
/DS0: J2.10, RN1.2 (R1), U12.8 (MOTOR0)
/DS1: J2.12, RN1.3 (R2), U12.7 (MOTOR1)
/DS2: J2.14, RN1.5 (R4), U12.1 (MOTOR2)
/DTA: U1.10 (DTACK), U2.3 (I/O_2A)
/DTACK: J1.b8 (~DTACK), U2.11 (I/O_10A)
/FC0: J1.b21 (FC0), U1.30 (FC0)
/FC1: J1.b20 (FC1), U1.29 (FC1)
/FDCON_CS: U2.44 (I/O_33C), U12.18 (~CS)
/FDC_DIR: J2.18, U12.4 (DIRC)
/FDC_HD: J2.32, U12.9 (HDSEL)
/FDC_IP: J2.8, RN1.4 (R3), U12.11 (~IP)
/FDC_RD: J2.30, RN1.6 (R5), U12.44 (~RD)
/FDC_STEP: J2.20, U12.50 (STEP)
/FDC_T0: J2.26, RN1.7 (R6), U12.10 (~TR00)
/FDC_WD: J2.22, U12.3 (WD)
/FDC_WG: J2.24, U12.49 (WG)
/FDC_WPRT: J2.28, RN1.8 (R7), U12.12 (~WPRT)
/IPL0: J1.b27 (~IPLO), U1.27 (IPL0)
/IPL1: J1.b29 (~IPL1), U1.26 (IPL1)
/LDS: U1.8 (LDS), U2.12 (I/O_11A)
/MA0: U2.67 (I/O_47D), U8.9 (A0), U9.9 (A0), U10.9 (A0), U11.9 (A0)
/MA1: U2.66 (I/O_46D), U8.10 (A1), U9.10 (A1), U10.10 (A1), U11.10 (A1)
/MA2: U2.65 (I/O_45D), U8.11 (A2), U9.11 (A2), U10.11 (A2), U11.11 (A2)
/MA3: U2.64 (I/O_44D), U8.12 (A3), U9.12 (A3), U10.12 (A3), U11.12 (A3)
/MA4: U2.63 (I/O_43D), U8.14 (A4), U9.14 (A4), U10.14 (A4), U11.14 (A4)
/MA5: U2.41 (I/O_30C), U8.15 (A5), U9.15 (A5), U10.15 (A5), U11.15 (A5)
/MA6: U2.61 (I/O_41D), U8.16 (A6), U9.16 (A6), U10.16 (A6), U11.16 (A6)
/MA7: U2.62 (I/O_42D), U8.17 (A7), U9.17 (A7), U10.17 (A7), U11.17 (A7)
/MA8: U2.42 (I/O_31C), U8.18 (A8), U9.18 (A8), U10.18 (A8), U11.18 (A8)
/MA9: U2.68 (I/O_48D), U8.5 (A9), U9.5 (A9), U10.5 (A9), U11.5 (A9)
/MOTOR_ON: J2.16, U12.5 (DR1), U12.6 (DR0), U12.45 (DR2)
/RAS: U2.2 (I/O_1A), U8.4 (~RAS), U9.4 (~RAS), U10.4 (~RAS), U11.4 (~RAS)
/RDH: U2.5 (I/O_4A), U5.21 (OE_L)
/RDL: U2.9 (I/O_8A), U4.19 (CE)
/RDW: J1.b7 (~DRW), U2.39 (I/O_28C), U7.3 (WR), U12.16 (WR)
/RESET: J1.b12 (~RESETCPU), U1.19 (HALT), U1.20 (RESET), U2.17 (INP4/CLK1)
/RESFDC: U2.47 (I/O_36C), U12.15 (~MR)
/RW: U1.9 (R/W), U2.14 (INP1), U4.1 (A->B), U5.3 (DIR), U8.3 (~WR), U9.3 (~WR), U10.3 (~WR), U11.3 (~WR)
/UDS: U1.7 (UDS), U2.10 (I/O_9A)
/VPA: J1.b16 (~VPA), U1.23 (VPA)
/VSYNC: J1.b15 (VSYNCH), U12.35 (DSKCHG)
/WRH: U2.6 (I/O_5A), U5.1 (CP_AB), U5.2 (S_AB)
GND: C1.2, C2.2, C5.2, C6.2, C7.2, C8.2, C9.2, C10.2, C11.2, C12.2, C13.2, C14.2, C15.2, C16.2, D1.1 (K), H1.1, H2.1, J1.a1 (GND), J1.a7 (A19), J1.a8 (A18), J1.a26 (SP2), J1.a28 (SP1), J1.a29 (SP0), J1.b1 (GND), J1.b10 (~BR), J1.b26 (SP3), J2.1, J2.3, J2.5, J2.7, J2.9, J2.11, J2.13, J2.15, J2.17, J2.19, J2.21, J2.23, J2.25, J2.27, J2.29, J2.31, J2.33, R1.1, R3.2, U0.2 (GND), U1.16 (GND), U1.17 (GND), U1.56 (GND), U1.57 (GND), U2.1 (GND), U2.35 (GND), U3.14 (GND), U3.22 (~OE/Vpp), U4.10 (GND), U5.12 (GND), U5.22 (S_BA), U5.23 (CP_BA), U6.1 (A->B), U6.10 (GND), U6.18 (B0), U6.19 (CE), U8.22 (~OE), U8.26 (GND), U9.22 (~OE), U9.26 (GND), U10.22 (~OE), U10.26 (GND), U11.22 (~OE), U11.26 (GND), U12.2 (GND), U12.27 (GND), U12.36 (GND), U12.39 (GND), U12.46 (PUMP), U12.47 (DRVTYP), X1.4 (GND)
unnamed: BT1.2 (-), D2.1 (K)
unnamed: C3.2, C4.2, C5.1, R4.2
unnamed: C17.2, D1.2 (A), D2.2 (A), U7.8 (GND)
unnamed: D3.2 (A), R1.2, R2.1
unnamed: J3.1, U0.3 (OUT)
unnamed: J3.2, U0.1 (IN)
unnamed: Q1.2 (B), R2.2
unnamed: Q1.3 (C), U7.1 (~CS)
unnamed: C1.1, U7.15 (XTAL_IN), Y3.2
unnamed: C2.1, U7.14 (XTAL_OUT), Y3.1
unnamed: C4.1, U12.42 (FE25)
unnamed: C3.1, U12.41 (FE50)
unnamed: C6.1, R4.1, U12.40 (FILT)
unnamed: U12.38 (OSC1), Y2.2
unnamed: U12.37 (OSC2/CLK), Y2.1
unnamed: R3.1, U12.48 (SETCU)

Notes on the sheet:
N/C
DENSITY SEL
MOTOR 0
MOTOR 1
DS0
READY / Disc Chan.
DS1

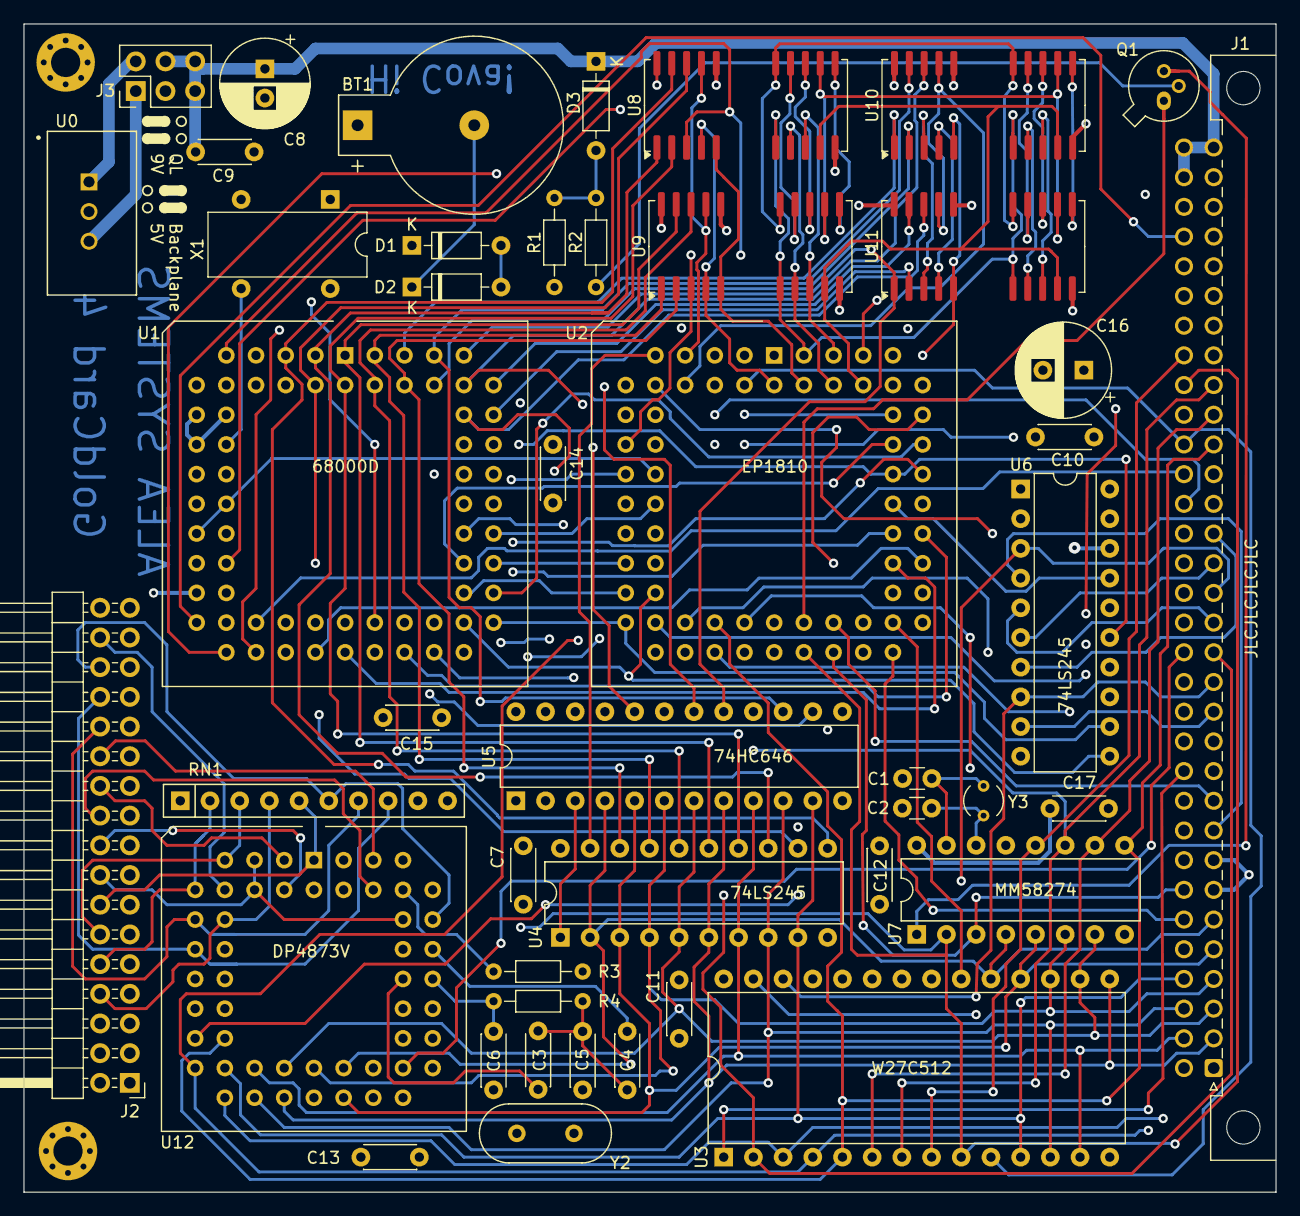
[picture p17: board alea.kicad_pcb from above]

Board: 4 copper layers, 107.1 x 99.9 mm, 48 parts (0 on the bottom side), 129 nets.

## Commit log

2025-06-22 fix fault in pcb of FDC and add orignal + alea versions
    [GoldCard-B_Cu.gbr, GoldCard-B_Mask.gbr, GoldCard-B_Paste.gbr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]
2025-06-25 remove last extra vias
    [Original.kicad_sch, alea.kicad_pcb]
2025-06-29 2025/06 update
    [alea.kicad_pcb, alea.kicad_sch]
2025-06-30 update again for bad FDC pinout
    [Original.kicad_sch, alea.kicad_pcb, alea.kicad_sch]
2025-07-05 fix values
    [Original.kicad_sch, alea.kicad_pcb, alea.kicad_sch]
2025-08-05 small update in alea
    [alea.kicad_pcb, alea.kicad_sch]
